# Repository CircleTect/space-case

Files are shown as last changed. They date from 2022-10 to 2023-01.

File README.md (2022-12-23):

<!-- PROJECT LOGO -->
<br />
<div align="center">
  <a href="https://circlestudio.co">
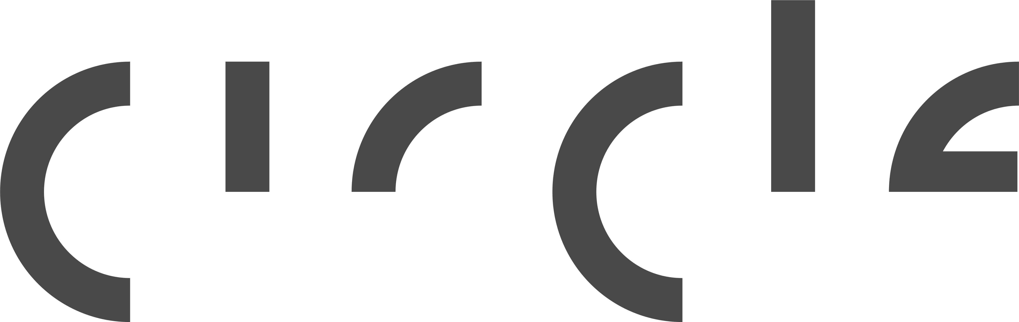
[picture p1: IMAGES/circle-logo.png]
    
  </a>

  <h3 align="center">Space Case: Makers Edition</h3>

  <p align="center">
    A 3D printable mini-itx case platform maintained by Circle Studio. 
  </p>
</div>

<!-- ABOUT THE PROJECT -->
## About

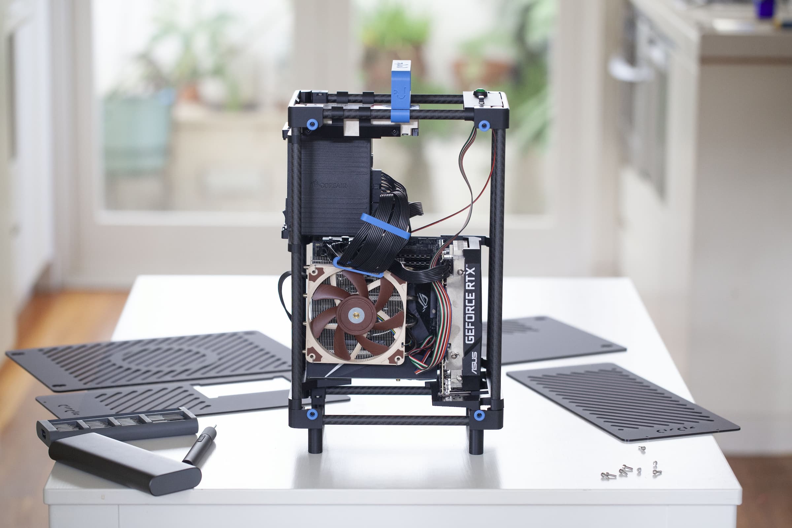
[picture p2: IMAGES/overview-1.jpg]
Space Case Overview Space Case


The Space Case is a mini-itx case that is easy to build at home with a 3d printer and off-the-shelf components. 

[Video Introduction](https://www.youtube.com/watch?v=Zg2zSBpEYaU&ab_channel=CircleStudio)

[Build Setup Guide](https://youtu.be/Fd_JhfacgS0)

[Assembly Guide Part 1](https://youtu.be/junsv9OFG80)

It features:

* Full length 3-slot (or 4-slot with the 4-slot mod) GPU support up to 330mm long.
* Riser-card free design (reduces compatibility issues and cost). 
* up to 280mm radiator support. 
* CPU cooler height up to 149mm. 
* SFX PSU support.
* 3.5" HDD support. 
* GPU and mobo I/O egress from base of the case. 
* Optional I/O panel at the top of the case. 
* Convenient & sturdy handle.
* 16.7 litres.

<!-- GET STARTED -->
## How to build

**NOTE: The design is currently in beta testing. Be prepared to tinker.**   
Check the [changelog](CHANGELOG.md) for latest changes. 

[Build Setup Guide](https://youtu.be/Fd_JhfacgS0)

[Assembly Guide Part 1](https://youtu.be/junsv9OFG80)

* Step 1: Decide on 3-Slot or 4-Slot build. Source components. Component list is [here.](04_COMPONENTS/COMPONENT_LIST.md) 
* Step 2: Print the [parts.](02_3D%20PRINT%20FILES/) 
* Step 3: (Optional) Source laser cut panels using [these cut files.](03_LASER%20CUT%20FILES/)
* Step 4: Assemble using [this guide.](https://youtu.be/junsv9OFG80) 
* Step 5: Enjoy your new case!

</br>

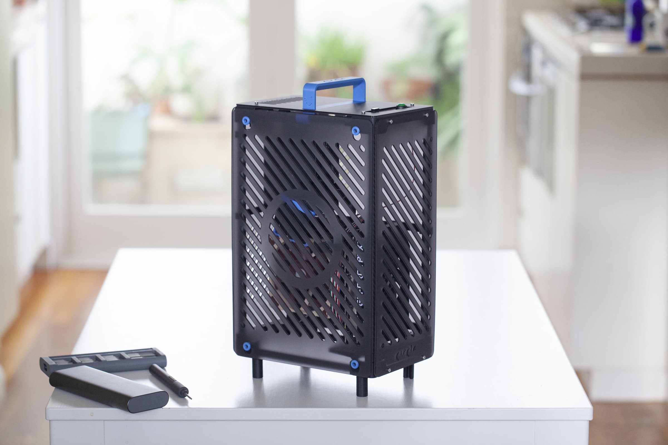
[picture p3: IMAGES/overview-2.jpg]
Space Case Overview Space Case


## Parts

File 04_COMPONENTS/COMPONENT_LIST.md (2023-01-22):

## 01. Frame tubing

#### - Design requirements

* "Long tube" - 12mm OD - 380MM **QTY 4**
* "Short tube for 3-Slot build" -  12mm OD - 218mm **QTY 4** (NOTE: extendable to 4-slot length with addition of extender printed parts)
* "Short tube for 4-Slot build native" - 12mm OD - 238mm **QTY 4**

#### - Tube material types

Recommended to buy 3 x 1000mm lengths and cut to length with a hand-saw / coping saw / drop saw / bandsaw, etc.  This is the most optimal length for shipping and minimising off-cuts. 

Tube material types in order of preference:

* **Carbon fibre - wrapped.** Best looking, but most expensive. <br>
[Purchase link 1 - eBay Aus](https://www.ebay.com.au/itm/142235086258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),
[Purchase link 2 - Amazon US](https://a.co/d/00u7MOV)
[Purchase link 3 - Specialty store AU](http://www.carbonfiber.com.au/prod83.htm)
* **Carbon fibre - pulltruded.** Great performing, more affordable than wrapped. <br>
[Purchase link 1 - Specialty AU](http://www.carbonfiber.com.au/prod24.htm),
[Purchase link 2 - Amazon US](https://a.co/d/2IjlKr8)
* **Aluminium tube.** Light, cheap, not as easy to find in 1000mm lengths. 
* **Timber dowel** Light, cheap, easy to source. Not as rigid or as good looking as carbon or aluminium. 

## 02. Screw hardware

* M3x10mm screws  **QTY 50** [Example link](https://a.co/d/0MslMnX)
* M3 nuts  **QTY 50** [Example link](https://a.co/d/hjAK4r9)

## 03. I/O Panels

* Standard USB 2 'Cheap eBay #1' I/O: 2 x USB A 2.0, Audio in - Audio out [Example link](https://www.ebay.com.au/itm/234794490206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) TESTED AND WORKING
* Standard USB 3 'Cheap eBay #2' I/O: 2 x USB A 3.0, Audio in - Audio out [Example link](https://www.ebay.com.au/itm/224887554100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) TESTED - NOT WORKING WITH EXISTING 3D PRINTED PARTS, will need some modification. 

## 04. Power switch

* Momentary Push Button Switch SPST - Option 1 - Amazon [Example link](https://a.co/d/9fXicy8)
* Momentary Push Button Switch Metal Chassis - Option 2 with light - Amazon [Example link](https://a.co/d/cJvIqA9)
* Momentary Push Button Switch - Option 3 - AliExpress [Example link](https://www.aliexpress.com/item/1005004340919460.html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)

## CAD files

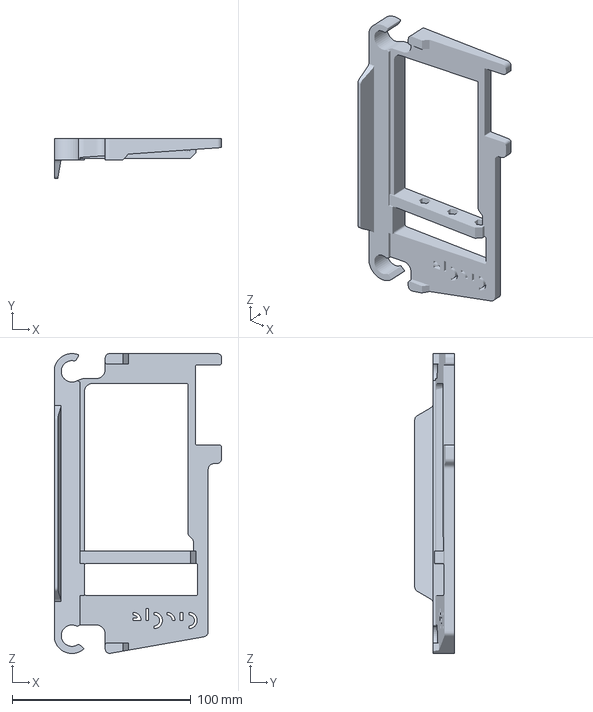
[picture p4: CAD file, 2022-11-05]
02_3D PRINT FILES/3-Slot Build/02_X1_3-SLOT_GPU_SUPPORT_V6_BLK.3mf
93.8 x 22.2 x 168.0 mm

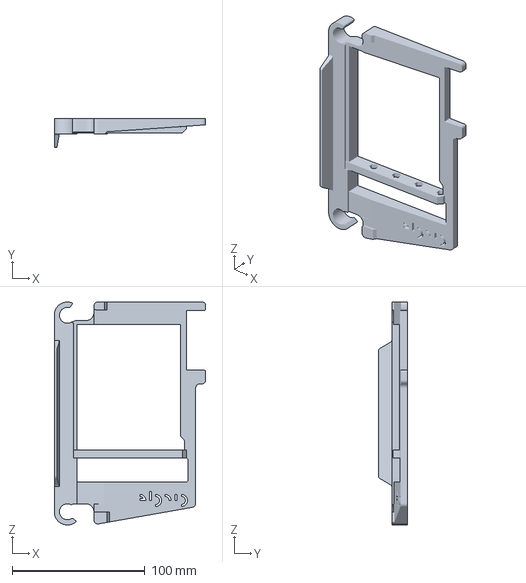
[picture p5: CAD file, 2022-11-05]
02_3D PRINT FILES/4-Slot Build/02_X1_4-SLOT_GPU_SUPPORT_V6_BLK.3mf
114.1 x 22.2 x 168.0 mm

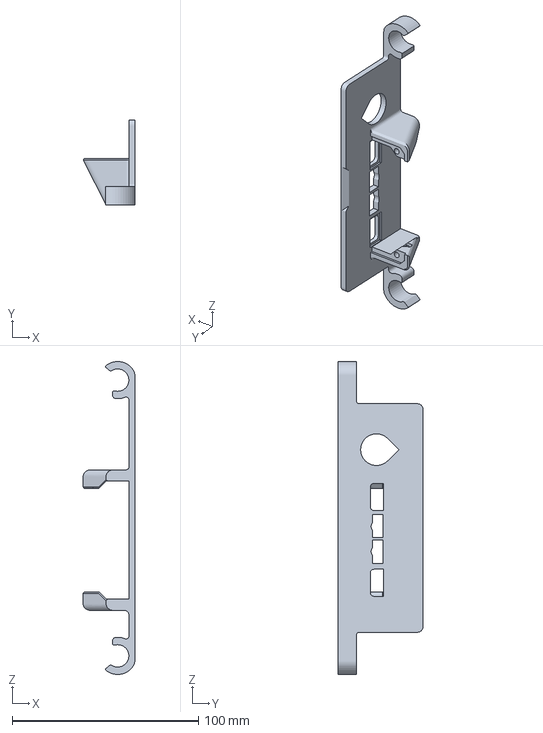
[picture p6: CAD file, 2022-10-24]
02_3D PRINT FILES/IO Panels/Cheap_Ebay-1_IO_PANEL_V6_16MM_BLK.3mf
27.8 x 45.7 x 168.1 mm

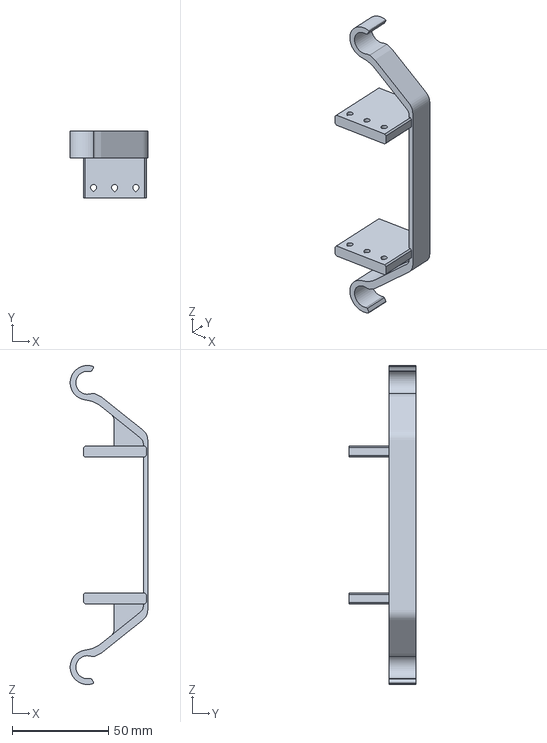
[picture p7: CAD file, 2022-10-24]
02_3D PRINT FILES/OPTIONAL_X2_2.5_DRIVE_SUPPORT_V3_BLK.3mf
40.4 x 35.0 x 166.1 mm

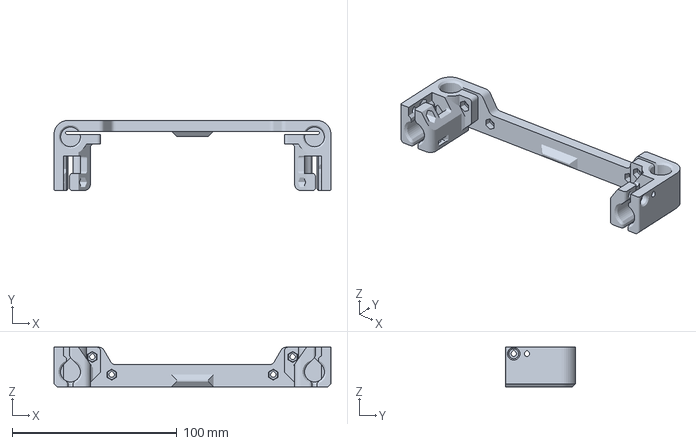
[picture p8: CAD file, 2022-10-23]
02_3D PRINT FILES/01_X4_PIPE_JOINT_V14_BLK.3mf
168.0 x 42.6 x 24.0 mm

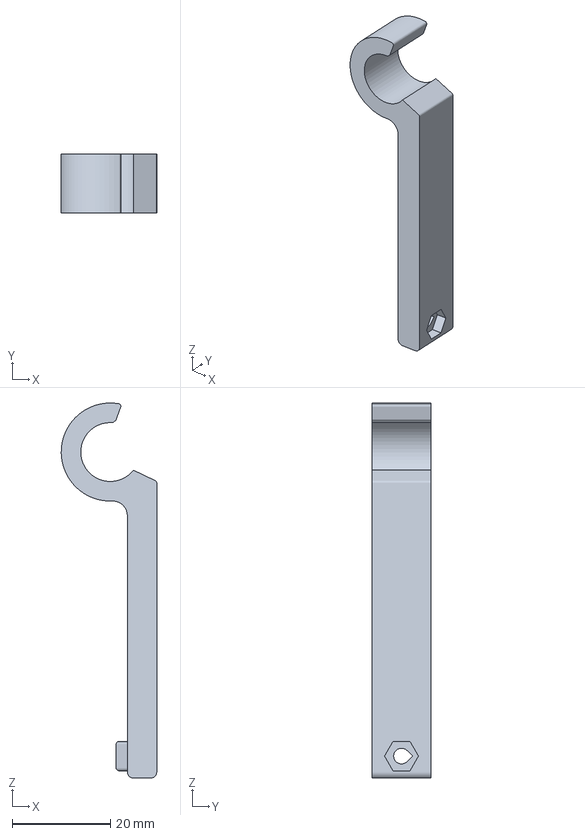
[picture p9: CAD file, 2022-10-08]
02_3D PRINT FILES/3-Slot Build/06_X2_3-SLOT_MOBO_BRACKET_LONG_V3_BLK.3mf
19.5 x 12.0 x 76.5 mm

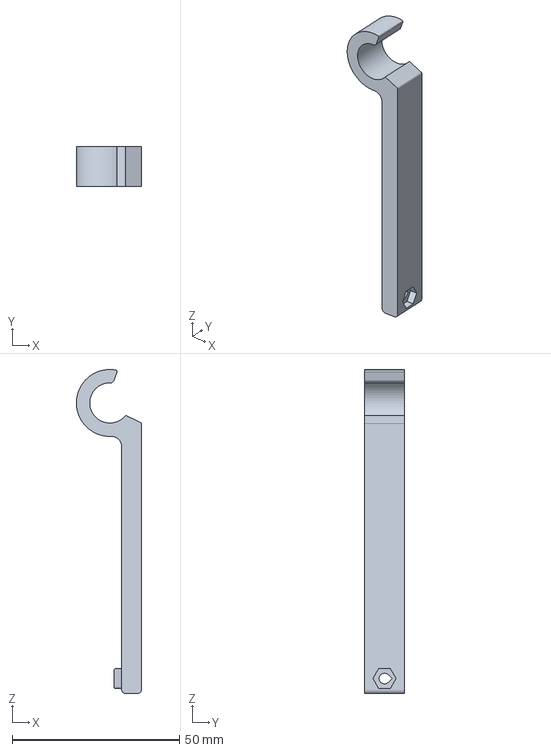
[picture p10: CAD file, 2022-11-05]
02_3D PRINT FILES/4-Slot Build/06_X2_4-SLOT_MOBO_BRACKET_LONG_V3_BLK.3mf
19.5 x 12.0 x 96.8 mm

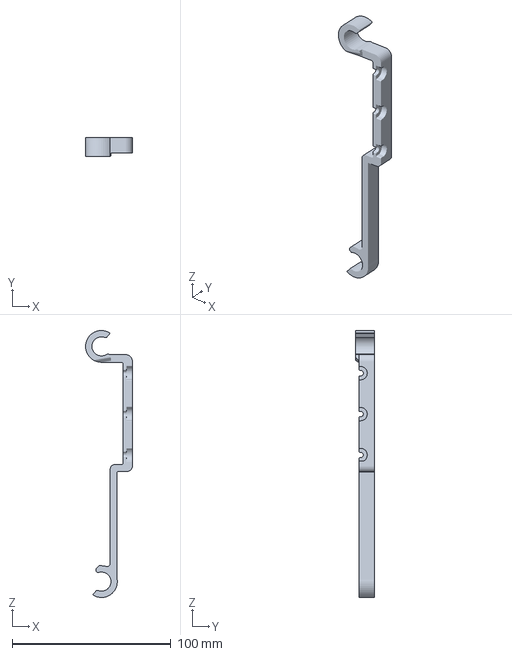
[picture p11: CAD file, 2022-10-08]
02_3D PRINT FILES/09_X1_PSU_BRACKET_UPPER_V3_BLK.3mf
29.5 x 12.0 x 168.0 mm

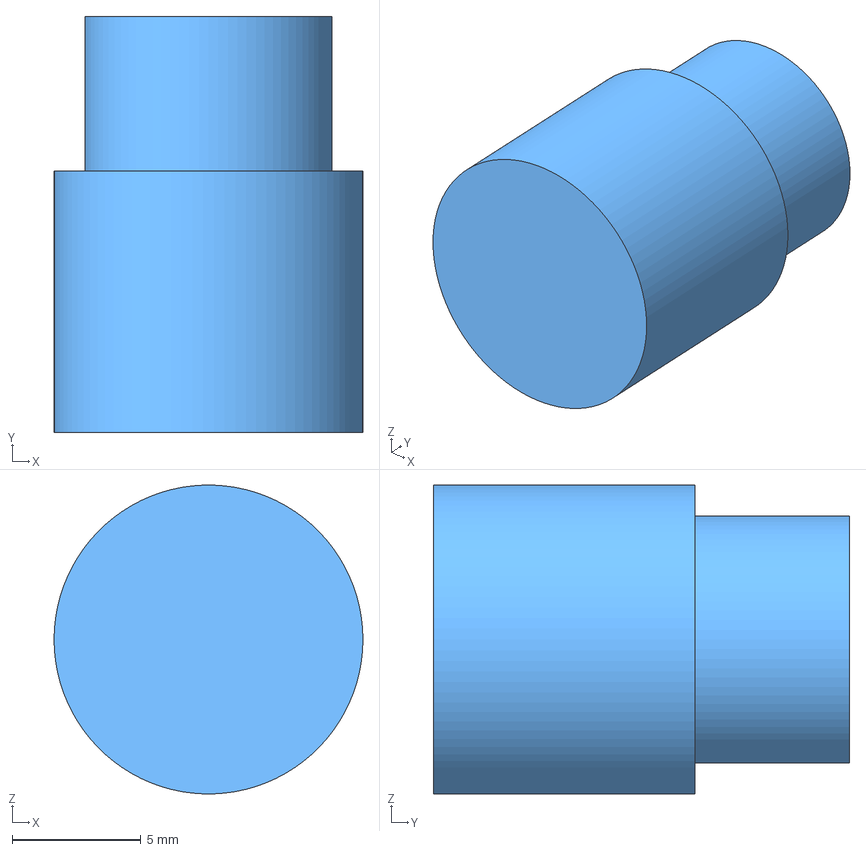
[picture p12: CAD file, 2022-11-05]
02_3D PRINT FILES/4-Slot Build/01B_X8_4-SLOT_PIPE_EXTENSION_V1.3mf
12.0 x 16.2 x 12.0 mm

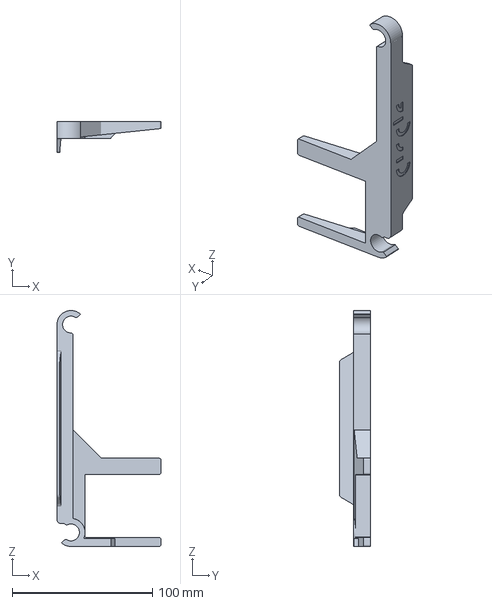
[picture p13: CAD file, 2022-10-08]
02_3D PRINT FILES/03_X1_MOBO_SUPPORT_V3_BLK.3mf
74.1 x 22.2 x 168.0 mm

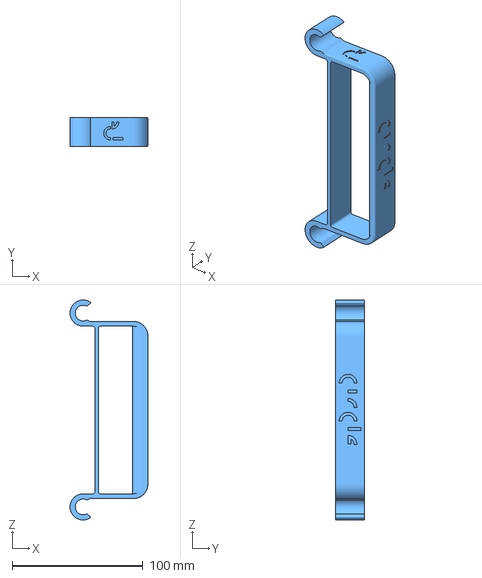
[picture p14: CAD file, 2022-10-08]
02_3D PRINT FILES/04_X1_HANDLE_V4_BLU.3mf
59.5 x 22.0 x 168.0 mm

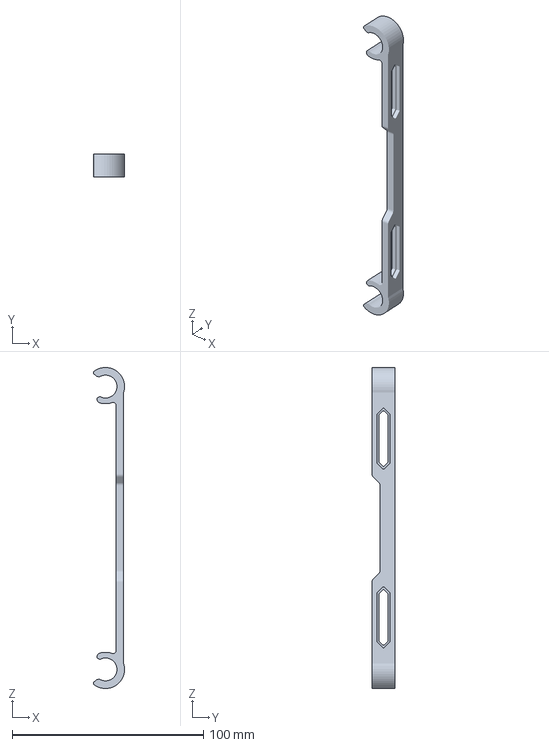
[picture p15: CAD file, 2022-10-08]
02_3D PRINT FILES/OPTIONAL_X2_FAN_BRACKET_V3_BLK.3mf
16.3 x 12.0 x 168.0 mm

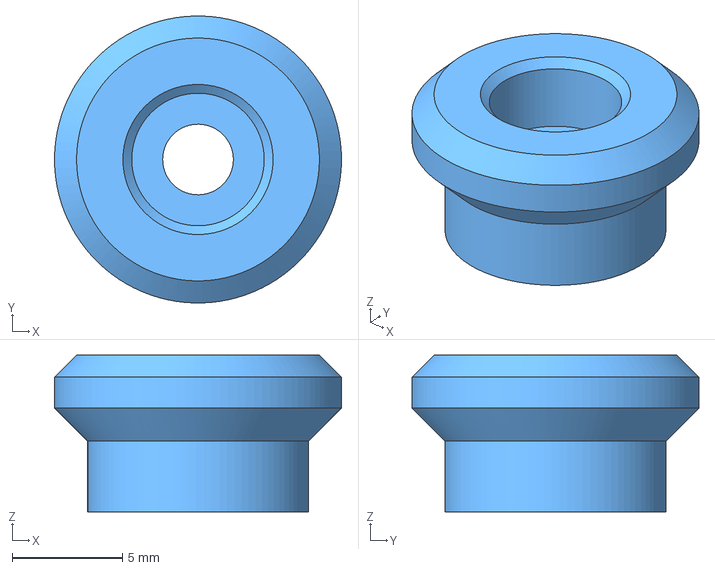
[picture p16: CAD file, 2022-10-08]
02_3D PRINT FILES/11_X8_PANEL_PIN_V1_BLU.3mf
13.0 x 13.0 x 7.10 mm

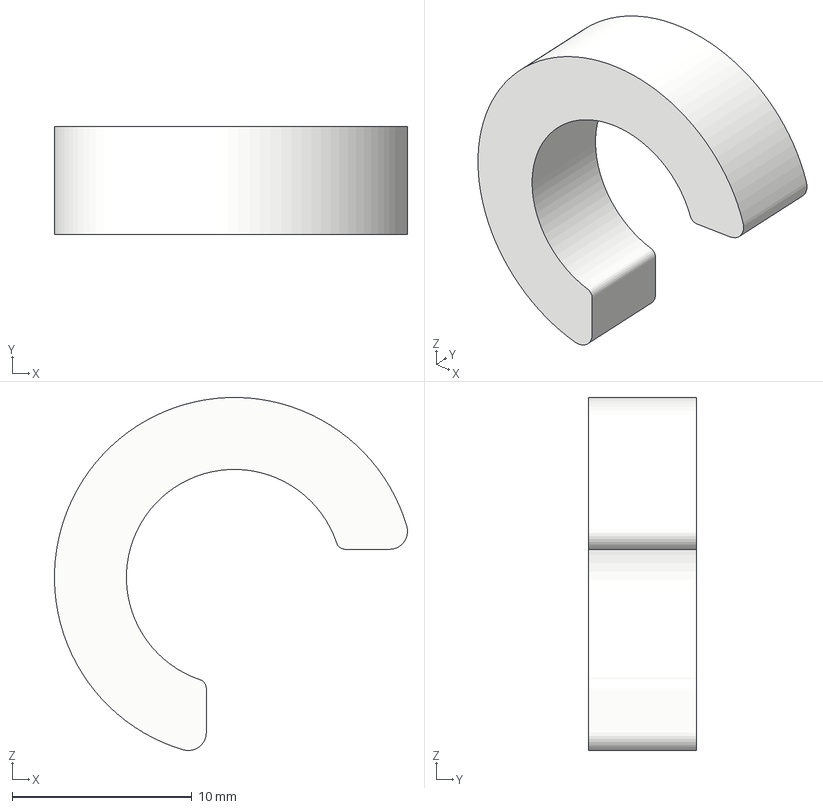
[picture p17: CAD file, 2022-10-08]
02_3D PRINT FILES/10_X2_PLATE_CLIP_V1_BLU.3mf
19.6 x 6.00 x 19.6 mm

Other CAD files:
02_3D PRINT FILES/IO Panels/Cheap_Ebay-1_IO_PANEL_V6_12MM_BLK.3mf
02_3D PRINT FILES/OPTIONAL_X2_CABLE_COMB_V2_BLU.3mf
02_3D PRINT FILES/OPTIONAL_X2_RAD_BRACKET_V1_BLK.3mf
02_3D PRINT FILES/07_X2_MOBO_BRACKET_SHORT_V3_BLK.3mf
02_3D PRINT FILES/05_X4_FOOT_V2_BLK.3mf
02_3D PRINT FILES/08_X1_PSU_BRACKET_LOWER_V3_BLK.3mf
02_3D PRINT FILES/OPTIONAL_X2_3.5_DRIVE_SUPPORT_V4_BLK.3mf

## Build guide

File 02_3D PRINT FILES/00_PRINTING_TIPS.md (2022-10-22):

### Printing Tips

* Print in order of the file numbers for optimal assembly.
* All parts are designed to print without supports. Every part has a natural flat side to align to the print bed. 
* Print in colours specified at the end of the filename, e.g. BLK (black), BLU (blue)
* Print QTY of parts denominated by the X number at the start of the filename.
* Filenames starting with OPTIONAL are just that - not necessary for the build but add additional functionality. 

### Print Settings

* Print with 'standard' settings in PLA or PETG for most parts: 0.2mm layer height is fine. 
* Some parts may require more strength, e.g. the 'FOOT' part requires more wall layers (at least 3).

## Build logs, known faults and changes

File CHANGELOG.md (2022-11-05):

# Changelog

## v1.0.3

### Added
- 4-Slot GPU support. 
- Requires native 'short tube' length of 238mm, or 3-Slot 218mm tubes with 3d printable extenders.

### Improvements
- Fixed a screw hole size issue on the IO panels. 
- Improved 2.5" drive caddy design. 

## v1.0.2

### Improvements
- Major improvement to pipe joints allowing tensioning of the shorter rods, creating a more solid frame.
- Minor adjustment to IO panel brackets to account for slight modification of the above pipejoints.  

## v1.0.1

### Added
- 3 x 2.5" drive support.
- 16MM vandal switch version of 'cheap eBay #1' I/O panel. 

### Improvements
- Edited 'cheap eBay #1' I/O panel to support PCB mounting via M3x10mm screw + hex nut. Previous design required thread cutting screw. 

## v1.0.0

### Added
- Initial commit. Space Case: Makers Edition launched.

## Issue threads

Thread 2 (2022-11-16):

Dual radiator and D5 pump support?

fabioneves, 2022-11-16:
Hello,

Any chance of having a version of a dual radiator 280 setup? (top/bottom)
Also having space to fit a D5 would be awesome.

Great job,
Thanks!

CircleTect, 2022-12-24:
There's plenty of room for a D5 already - just need to make a bracket for it.

The radiator (240 or 280) is designed to fit on the frame in the location indicated in the [video here](https://youtu.be/Zg2zSBpEYaU?t=307).

fabioneves, 2022-12-24:
Thank you for the answer. Unfortunately a single radiator for todays hardware is not enough.

Merry Xmas, keep up the good work 😊

Closed 2023-06-24.

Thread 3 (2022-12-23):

3d print the panels

sakoula, 2022-12-23:
Hi

quick question, do you recommend 3d print the side panels?

btw this is a super amazing project!!!!

CircleTect, 2022-12-24:
The side panels are way too big to 3d print - I recommend laser cutting them instead.

It would be a pretty cool challenge to come up with panels that can be 3d printed though..

sakoula, 2022-12-24:
hi, thanks for the reply!!!

your design is super cool!!!

I am starting to source the bom. I will try to 3d print the side panels since I do not have access to laser cutting.

btw another option is coroplast which it is very easy to cut with an hobby knife (inspired by the voron 3d print community)

https://www.michaels.com/plastic-corrugated-board-by-creatology/M10567770.html

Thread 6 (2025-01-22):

Entire column of IO blocked by CF rod near IO panel.

mhu900, 2025-01-22:
I can only access 1 usb port, an ethernet port and a line in port. the vast majority of my IO doesn't have the clearance to plug anything in  because the CF rod doesn't leave enough space.

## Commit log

2022-10-22 Added 3 x 2.5" drive support
    [3.5_DRIVE_SUPPORT_V4_BLK.3mf, Cheap_Ebay#1_IO_PANEL_V3_BLK.3mf, Cheap_Ebay#1_IO_PANEL_V4_12MM_BLK.3mf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]
2022-10-22 Cloning error fix
    Bad characters in filenames preventing successful clone.
    [Cheap_Ebay-1_IO_PANEL_V4_12MM_BLK.3mf, Cheap_Ebay-1_IO_PANEL_V4_16MM_BLK.3mf]
2022-10-22 Updated 3 x 2.5" drive design
    [OPTIONAL_X2_2.5_DRIVE_SUPPORT_V1_BLK.3mf, OPTIONAL_X2_2.5_DRIVE_SUPPORT_V2_BLK.3mf]
2022-10-23 Frame tension improvement
    [01_X4_PIPE_JOINT_V13_BLK.3mf, 01_X4_PIPE_JOINT_V14_BLK.3mf, Cheap_Ebay-1_IO_PANEL_V4_12MM_BLK.3mf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]
2022-10-24 Fixed issues
    [Cheap_Ebay-1_IO_PANEL_V5_12MM_BLK.3mf, Cheap_Ebay-1_IO_PANEL_V5_16MM_BLK.3mf, Cheap_Ebay-1_IO_PANEL_V6_12MM_BLK.3mf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]
2022-11-05 4-Slot updates
2022-11-05 Added 4-slot GPU compatibility
2022-11-05 4-slot GPU compatibility
    [01B_X8_4-SLOT_PIPE_EXTENSION_V1.3mf, 02_X1_3-SLOT_GPU_SUPPORT_V6_BLK.3mf, 02_X1_4-SLOT_GPU_SUPPORT_V6_BLK.3mf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]
2022-12-23 Added assembly guide part 1 to README
